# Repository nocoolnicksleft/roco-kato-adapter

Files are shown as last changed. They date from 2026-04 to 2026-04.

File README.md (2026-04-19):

# Roco N (and others) to Kato Unitrack Adapters

Parametric OpenSCAD adapter beds for N-scale [Roco](https://www.roco.cc/) track to connect to the [Kato Unitrack](https://www.katomodels.com/unitrack) system.

The adapters are printed and glued to the underside of Roco track pieces, adding a Kato-compatible sleeper bed with Unijoiner connectors so the Roco pieces plug straight into any Kato Unitrack layout.

25 pre-built configurations are included, covering all common Roco straights, curves and turnouts, plus sleeper belt fillers. Custom pieces and multi-piece layout plates can be generated with a few lines of OpenSCAD.

In general, they should work with any bedless Code 80 system. (Roco N, Fleischmann, Minitrix, Peco, Atlas) From personal experience, I recommend not mixing Minitrix and Roco track on the same base, as the slight difference in height can cause trouble.

You can use the stl files of the pre-built models with any slicer. If you want to work with custom settings or do other modifications you will need OpenSCAD, and Python 3 for the export script.

Use **0.1 mm layer height** and **supports** - both are required for successful prints (see Print Settings below).

---

## Pre-Built Models

Run `./export_stl.sh` to generate all STL files and preview images from the parameter sets in `Roco_Kato_Adapter.json`.

### Turnouts

| Model | Preview |
|---|:---:|
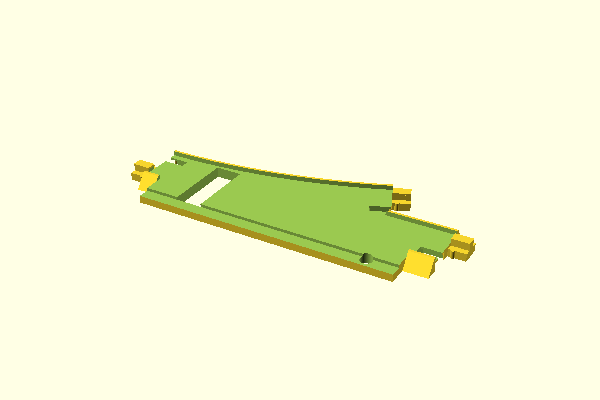
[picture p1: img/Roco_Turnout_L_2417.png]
| **Roco Turnout L 2417** - left, 24°, R194.6, with drive platform |  |
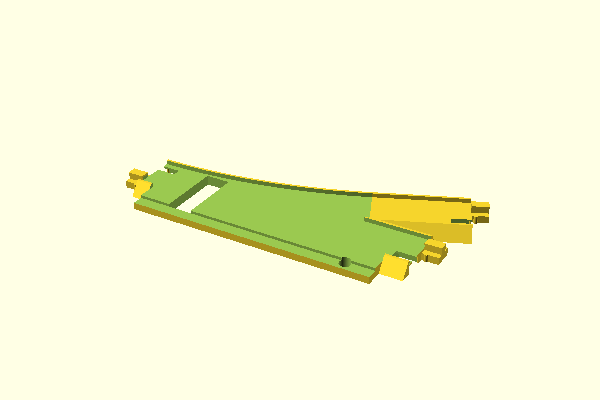
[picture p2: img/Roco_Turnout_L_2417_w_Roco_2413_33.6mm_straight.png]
| **Roco Turnout L 2417 w/ Roco 2413 33.6mm straight** on turnout |  |
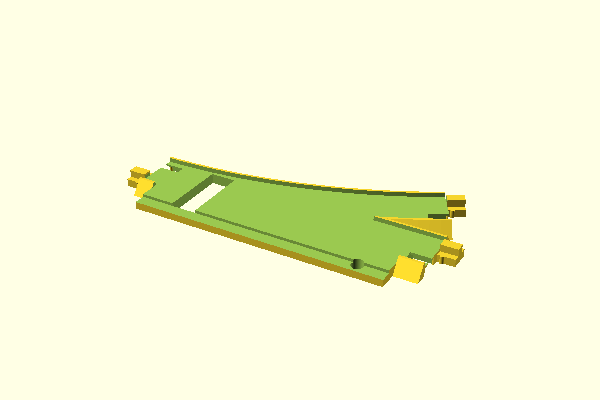
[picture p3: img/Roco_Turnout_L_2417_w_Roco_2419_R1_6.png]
| **Roco Turnout L 2417 w/ Roco 2419 R1 6°** - with 6° curve appended |  |
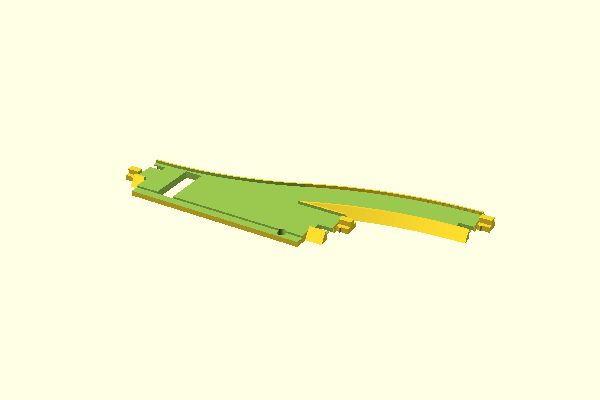
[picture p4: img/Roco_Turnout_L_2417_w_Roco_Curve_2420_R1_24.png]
| **Roco Turnout L 2417 w/ Roco Curve 2420 R1 24°** - with 24° S-curve appended |  |
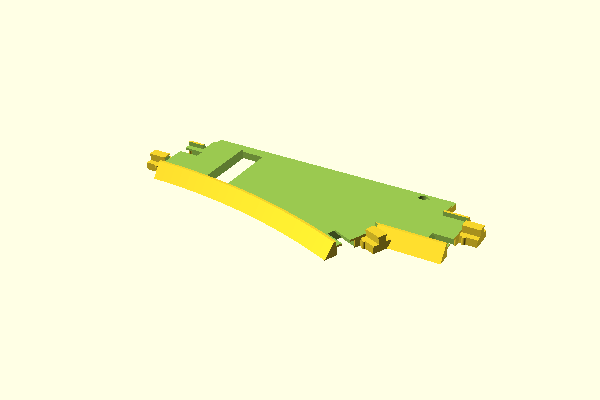
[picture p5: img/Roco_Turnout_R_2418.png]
| **Roco Turnout R 2418** - right 24°, R194.6, with drive platform |  |
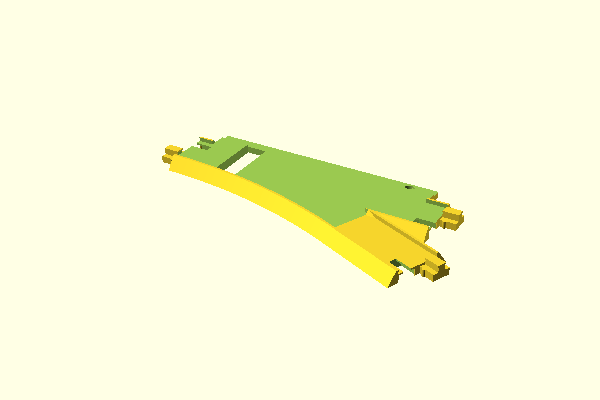
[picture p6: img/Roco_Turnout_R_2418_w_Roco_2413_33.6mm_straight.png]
| **Roco Turnout R 2418 w/ Roco 2413 33.6mm straight** |  |
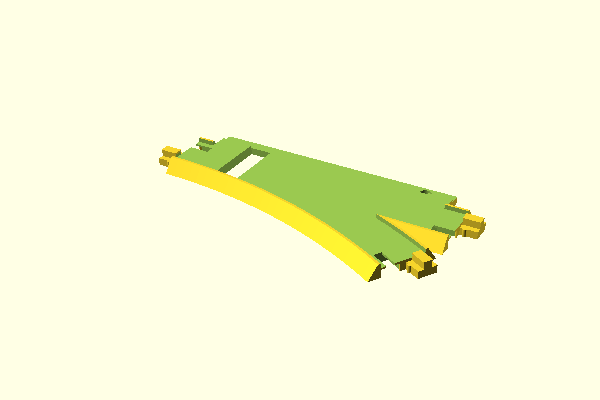
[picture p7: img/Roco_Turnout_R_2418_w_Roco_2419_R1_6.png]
| **Roco Turnout R 2418 w/ Roco 2419 R1 6°** |  |

### Straights and Decoupler

| Model | Preview |
|---|:---:|
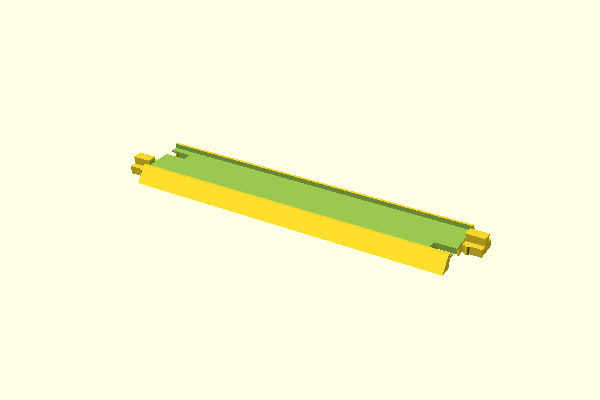
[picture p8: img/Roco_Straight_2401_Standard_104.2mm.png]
| **Roco Straight 2401** - 104.2 mm standard straight |  |
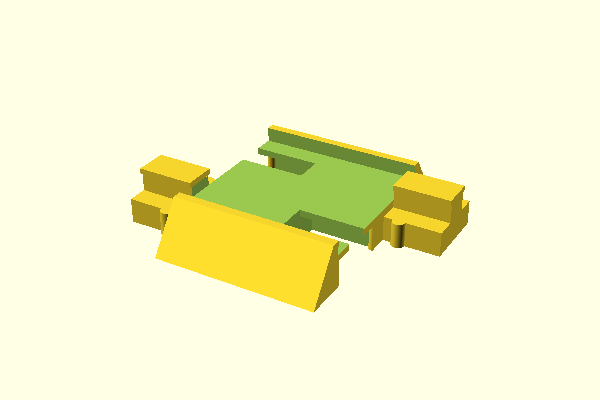
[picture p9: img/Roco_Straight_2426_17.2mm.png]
| **Roco Straight 2426** - 17.2 mm |  |
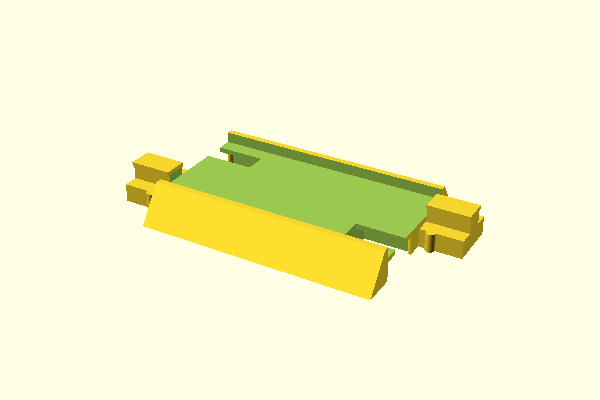
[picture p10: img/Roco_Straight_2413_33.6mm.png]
| **Roco Straight 2413** - 33.6 mm |  |
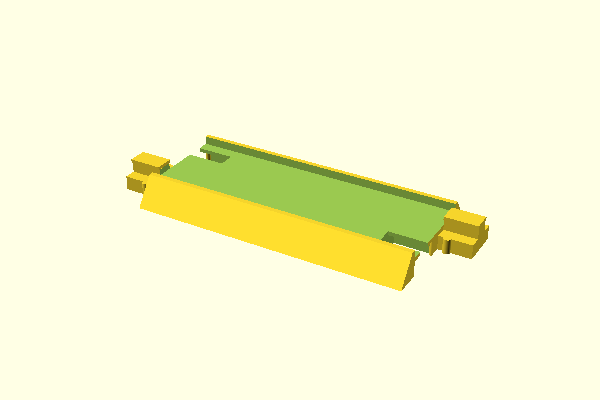
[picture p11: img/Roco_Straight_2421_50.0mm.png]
| **Roco Straight 2421** - 50.0 mm |  |
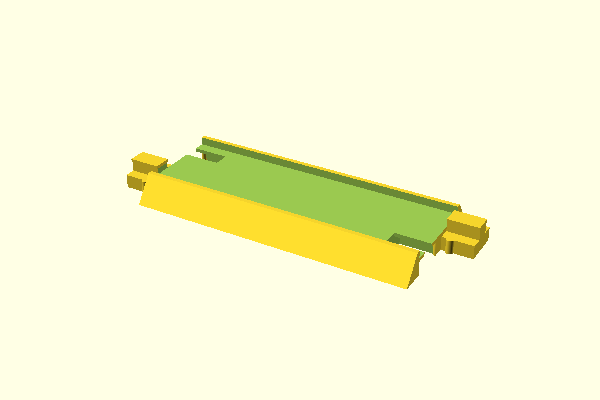
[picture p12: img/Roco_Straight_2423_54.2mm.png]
| **Roco Straight 2423** - 54.2 mm |  |
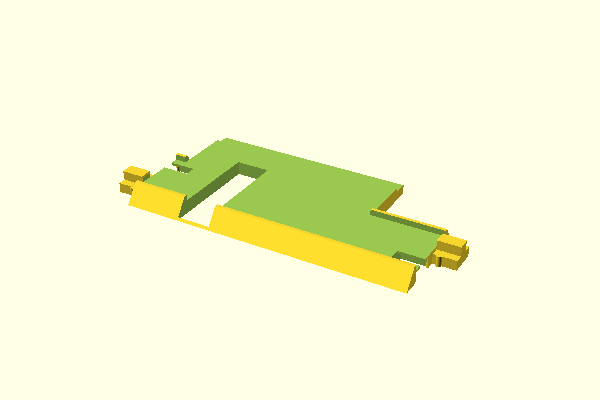
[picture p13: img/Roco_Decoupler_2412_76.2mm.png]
| **Roco Decoupler 2412** - 76.2 mm, with drive platform |  |

### Curves

| R1 (194.6 mm) | R2 (228.2 mm) | R3 / R3A / R4–R6 |
|:---:|:---:|:---:|
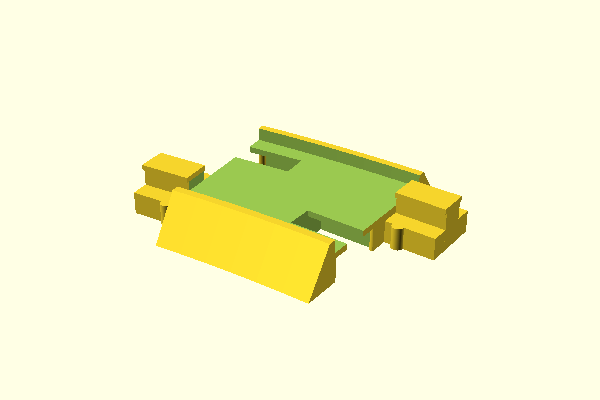
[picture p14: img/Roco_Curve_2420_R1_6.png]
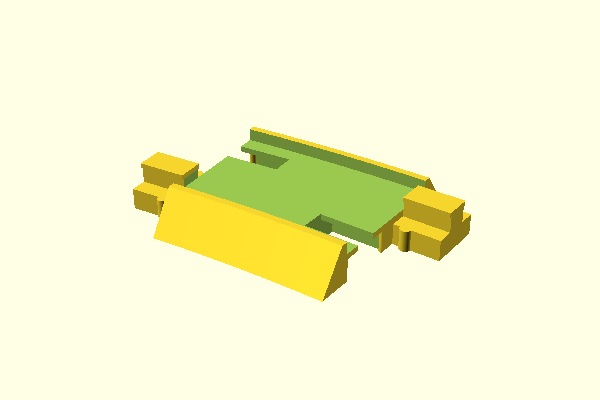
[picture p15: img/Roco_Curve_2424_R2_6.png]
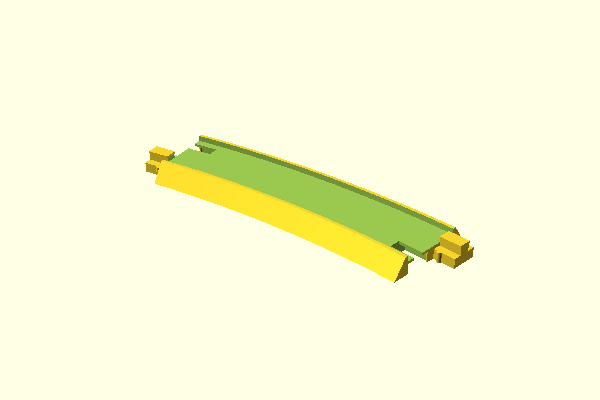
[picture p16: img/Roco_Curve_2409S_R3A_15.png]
| <br>**2420 R1 6°** | <br>**2424 R2 6°** | <br>**2409S R3A 15°** |
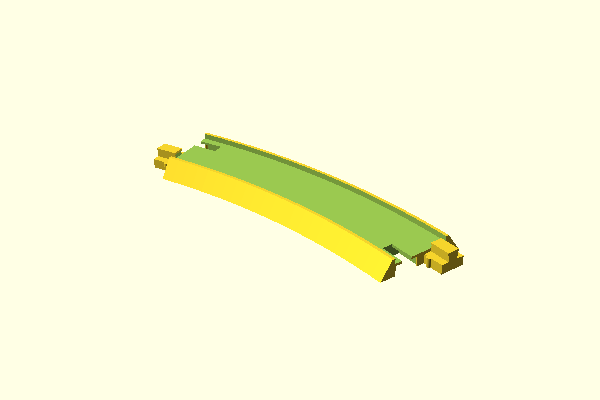
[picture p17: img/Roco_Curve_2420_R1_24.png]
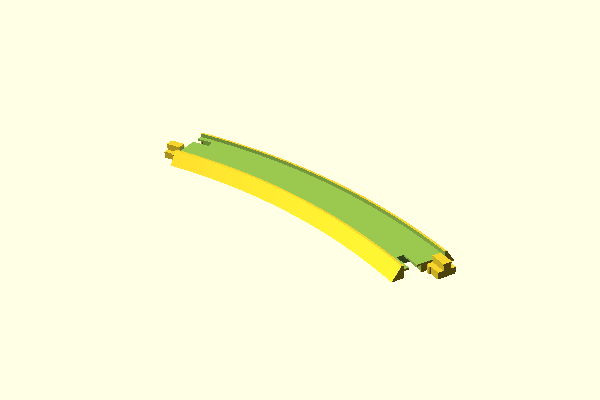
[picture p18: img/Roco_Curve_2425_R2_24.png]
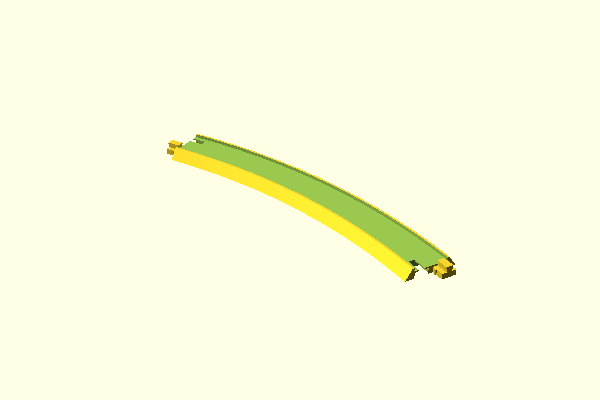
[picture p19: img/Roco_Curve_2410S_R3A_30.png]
| <br>**2420 R1 24°** | <br>**2425 R2 24°** | <br>**2410S R3A 30°** |
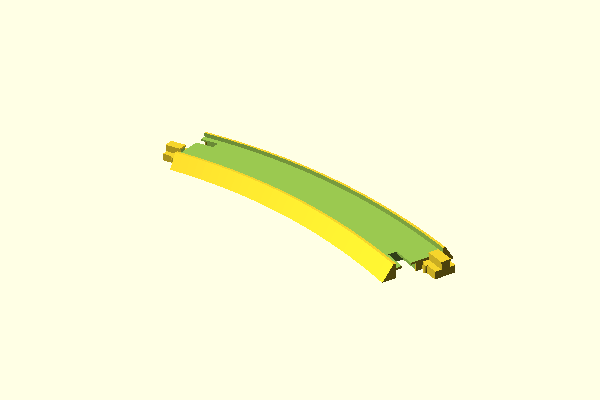
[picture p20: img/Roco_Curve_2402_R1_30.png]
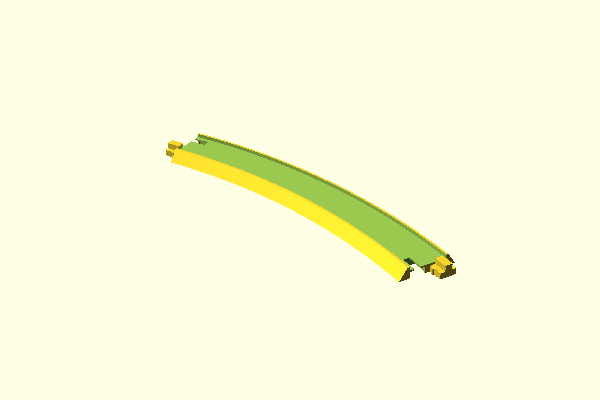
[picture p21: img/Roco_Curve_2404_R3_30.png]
| <br>**2402 R1 30°** | <br>**2403 R2 30°** | <br>**2404 R3 30°** |
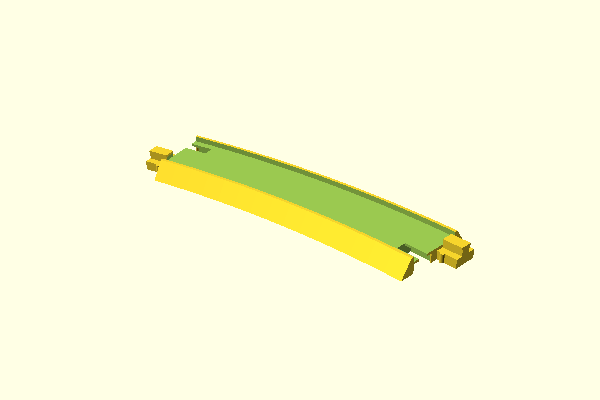
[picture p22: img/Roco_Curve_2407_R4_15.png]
| | | <br>**2407 R4 15°** |
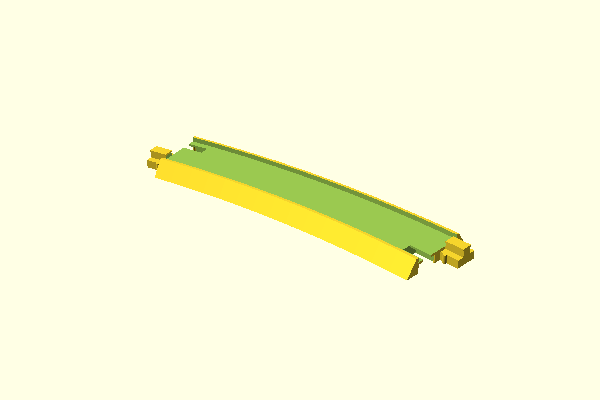
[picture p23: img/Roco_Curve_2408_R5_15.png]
| | | <br>**2408 R5 15°** |
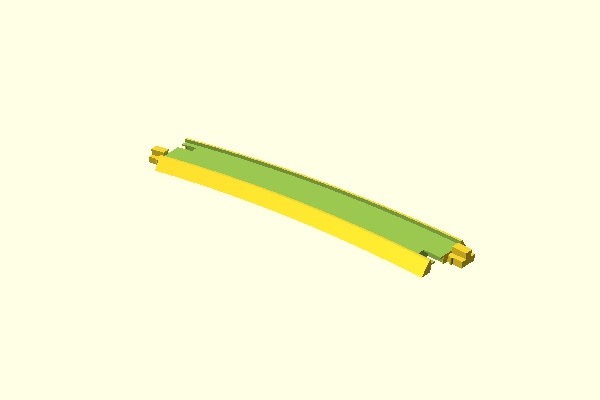
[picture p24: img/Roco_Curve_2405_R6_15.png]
| | | <br>**2405 R6 15°** |

### Sleeper Belts

Standalone strips of Roco-style sleepers for sections of track that need a base but no Kato adapter geometry — for example plain track glued directly to a baseboard. Each belt has sleepers, two longitudinal rail blocks, and rail clamps. End types are configurable per end: **Closed** (full sleepers to the edge), **Open** (rail blocks extend one pitch beyond the last sleeper for butting against an adjacent piece), or **Unijoiner** (right-side rail and sleeper halves cut back to clear Kato Unijoiner connectors, with a centre spine for rigidity).

| Model | Preview |
|---|:---:|
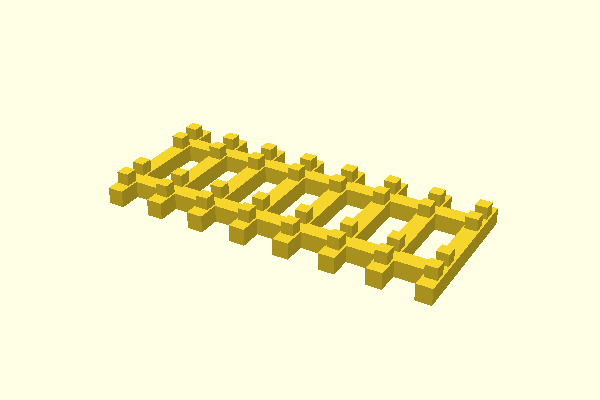
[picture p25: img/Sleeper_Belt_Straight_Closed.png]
| **Sleeper Belt Straight — Closed** — 8 sleepers, both ends closed |  |
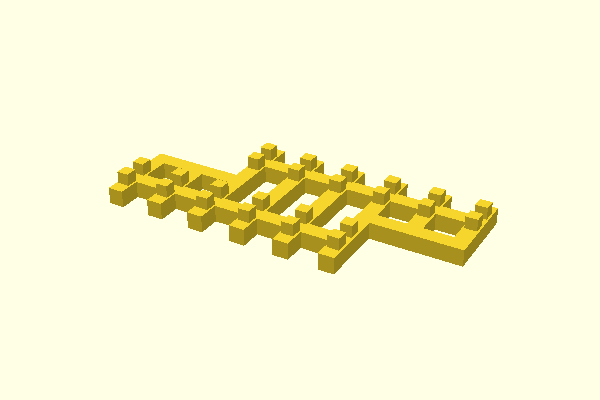
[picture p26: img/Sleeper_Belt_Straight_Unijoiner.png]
| **Sleeper Belt Straight — Unijoiner** — 8 sleepers, Unijoiner cutout at both ends |  |

Open `Roco_Sleeper_Belt.scad` in OpenSCAD to customise belt length, diameter (straight or any Roco/Kato radius), and per-end type. Parameter sets are defined in `Roco_Sleeper_Belt.json` and are included in the batch export.

---

## Usage

### Prepare the track

To accomodate for the Unijoiner receptable,the last two sleepers of the track must be cut and half of them removed. 

If you dont want to cut the sleepers, you can use SCAD to generate versions without Unijoiners and glue them together, or compose an individual model from multiple parts (see below). 

### 1: Print a Pre-Built Model

1. Run `./export_stl.sh` to generate all STL files into the `stl/` folder
   (also generates PNG previews into `img/` for reference).
2. Open the desired STL in desired Slicer and print.

Pre-built configurations are defined in `Roco_Kato_Adapter.json`. To use one directly in OpenSCAD:

```bash
openscad -o my_piece.stl -p Roco_Kato_Adapter.json -P "Roco Turnout L 2417" Roco_Kato_Adapter.scad
```

### 2: Customise a Single Piece

Open `Roco_Kato_Adapter.scad` in OpenSCAD. The **Customizer** panel (View → Customizer) exposes all parameters with drop-down lists of valid values. Adjust, preview, render, then export the STL.

You can also add a new entry to `Roco_Kato_Adapter.json` with your custom parameter values so it becomes part of the batch export.

### 3: Compose a Multi-Piece Layout Plate

For printing multiple connected pieces as a single object, use `layout.scad` as a starting point. It `include`s `Roco_Kato_Adapter.scad` and calls `roco_adapter()` multiple times, using the positioning helpers to chain pieces end-to-end exactly.

```openscad
layout_mode = true;          // suppresses the single-piece default render
include <Roco_Kato_Adapter.scad>

// Piece 1 at origin
roco_adapter(straight_length=104.2, branch_angle=24, radius=194.6, mirrored=false, ...);

// Piece 2 positioned at the straight exit of piece 1
after_straight_exit(sl=104.2)
    roco_adapter(straight_length=33.6, branch_angle=0, enable_entrance_unijoiner=false, ...);

// Piece 3 positioned at the curved exit of piece 1
after_curved_exit(r=194.6, w=24, csl=0, cca=0, m=false)
    roco_adapter(straight_length=104.2, branch_angle=24, enable_entrance_unijoiner=false, ...);
```

**Unijoiner rule for joined pieces:** at every internal joint (where two pieces meet and are printed as one), disable the unijoiner on **both** sides - the exit unijoiner of the upstream piece and the entrance unijoiner of the downstream piece. Only the outer ends that connect to actual Kato Unitrack need unijoiners.

**Always use the connecting_straight_length and connected_curve_angle** properties for pieces directly attached to a turnout. Directly joining other pieces may result in rendering artifacts.

---

## Parameters Reference

### Geometry

| Parameter | Default | Description |
|---|---|---|
| `straight_length` | 104.2 | Length of the straight entry section in mm; 0 to omit |
| `branch_angle` | 24 | Turnout/curve angle in degrees; 0 for straight-only adapter. Values: 0, 6, 15, 24, 30 |
| `radius` | 194.6 | Curve radius in mm. R1=194.6, R2=228.2, R3=261.8, R3A=295.4, R4=329.0, R5=362.6, R6=480 |
| `connecting_straight_length` | 0 | Straight section appended after the branch curve in mm; 0 to omit |
| `connected_curve_angle` | 0 | S-curve angle appended after the branch curve to make exits parallel; 0 to omit |
| `connected_curve_radius` | 194.6 | Radius of the S-curve in mm |
| `mirrored` | false | `false` = left turnout (curve toward +Y); `true` = right turnout (curve toward −Y) |

### Drive Platform (Point Motor Mount)

| Parameter | Default | Description |
|---|---|---|
| `drive_length` | 0 | Length of drive platform in mm; 0 to omit. Use 89 for Roco 2417/2418 |
| `drive_width` | 10 | Width of drive platform in mm |
| `drive_offset` | 6 | Distance from entry to start of drive platform |
| `drive_inset` | 4 | Depth of the recessed slot at the end of the platform |
| `drive_cableslot_diameter` | 4 | Diameter of cable hole in mm |
| `drive_cableslot_offset` | 80 | Position of cable hole from entry |

### Unijoiners

| Parameter | Default | Description |
|---|---|---|
| `enable_entrance_unijoiner` | true | Unijoiner at the entry end of the piece |
| `enable_exit_unijoiner_straight` | true | Unijoiner at the straight exit end |
| `enable_exit_unijoiner_curved` | true | Unijoiner at the curved (branch) exit end |

### Positioning Helpers (layout files only)

| Module | Description |
|---|---|
| `after_straight_exit(sl)` | Translates children `sl` mm along +X (to the straight exit of a piece with `straight_length=sl`) |
| `after_curved_exit(r, w, csl, cca, ccr, m)` | Translates and rotates children to the curved exit. Parameters match the preceding piece's `radius`, `branch_angle`, `connecting_straight_length`, `connected_curve_angle`, `connected_curve_radius`, `mirrored` |

---

## Building

### Assembly

Glue the adapter bed to the underside of the Roco track piece while the piece is connected to Kato Unitrack on all sides. This ensures correct alignment and compensates for any minor tolerance variation.

### Print Settings

| Parameter | Value |
|---|---|
| Layer Height | **0.1 mm** (critical - see note below) |
| Infill | 20% |
| Infill Pattern | Gyroid |
| Supports | **Yes** (critical - see note below) |
| Material | PLA or PETG |
| Walls / Perimeters | 3 |
| Tested on | Prusa MK3, PrusaSlicer 2.x |

> **Critical settings:** 0.1 mm layer height is required to resolve the fine detail of the Unijoiner plug and slot geometry - coarser layers will produce connectors that are too loose or too tight. The overhangs on the connector faces need support from the bed.

PETG is recommended where higher durability or temperature resistance is needed, but PLA works equally well in a typical indoor layout (results on floor heating may vary, depending on your temperature comfort zone).

---

## Physical Calibration

The nominal Roco track dimensions (radius, angle) published in catalogues do not perfectly match the manufactured parts. The Roco R1 turnout (2417/2418), for example, has a measured lateral branch offset of ≈ 16.2 mm versus the nominal 16.82 mm - a difference of less than a millimetre, but enough to cause the track to bow and open the rail contacts when inserted into a tightly printed adapter bed.

The adapter compensates for this silently: all parameters and JSON presets use the official nominal values as usual, and the correction (R1: 24°/194.6 mm → 23.2°/200 mm) is applied internally in `Roco_Kato_Adapter.scad`.

Calibration data is currently only available for **Roco R1**. If you have accurate measurements for other radii (R2–R6) or other manufacturers' track, I would be very pleased if you shared them - for example via a pull request or an issue on the repository. The more data that can be collected, the better the fit will be for everyone.

---
## Tinkerers' little helpers

Optimization, documentation and framework were assisted by AI, namely Github Copilot and Claude Sonnet.

## License

This work is licensed under [CC BY 4.0](https://creativecommons.org/licenses/by/4.0/).  
You are free to share and adapt it for any purpose, provided you give appropriate credit.

Contributions and improvements are welcome - please open a pull request or send them to the author.

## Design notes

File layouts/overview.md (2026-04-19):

# Layout Overview

| Layout | Preview |
|---|---|
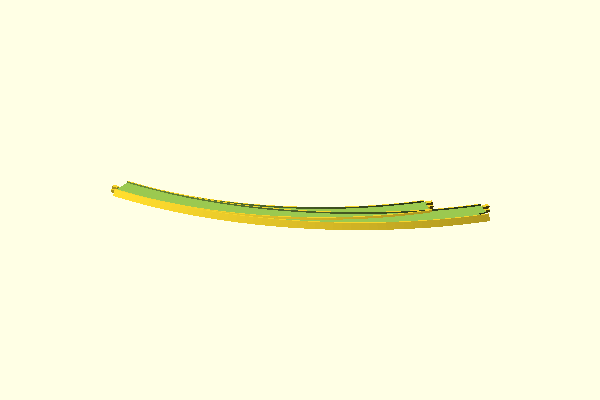
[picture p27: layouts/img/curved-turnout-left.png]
curved-turnout-left
| [Curved Turnout Left](scad/curved-turnout-left.scad) |  |
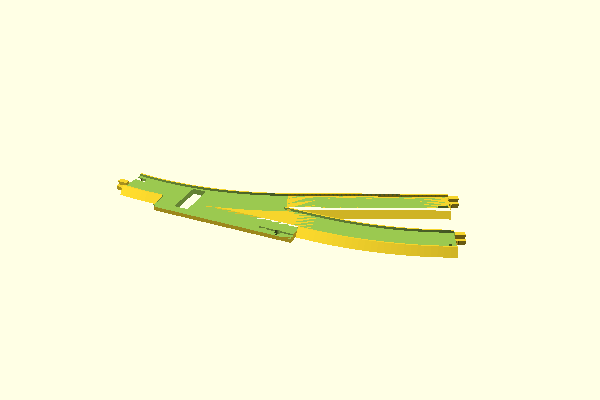
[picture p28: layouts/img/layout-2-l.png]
layout-2-l
| [Layout 2L — Turnout R + Curve R1 + Straight](scad/layout-2-l.scad) |  |
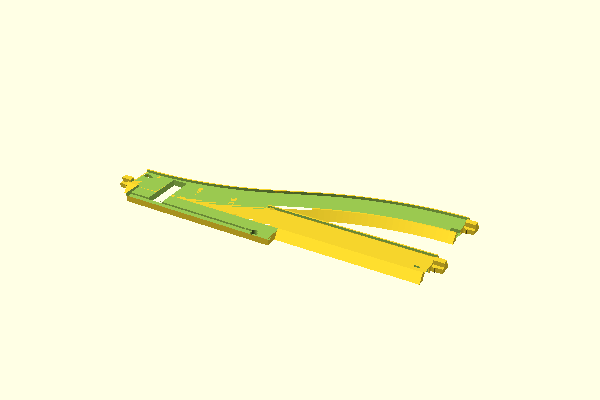
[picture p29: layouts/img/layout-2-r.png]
layout-2-r
| [Layout 2R — Turnout R + S-Curve 24°](scad/layout-2-r.scad) |  |
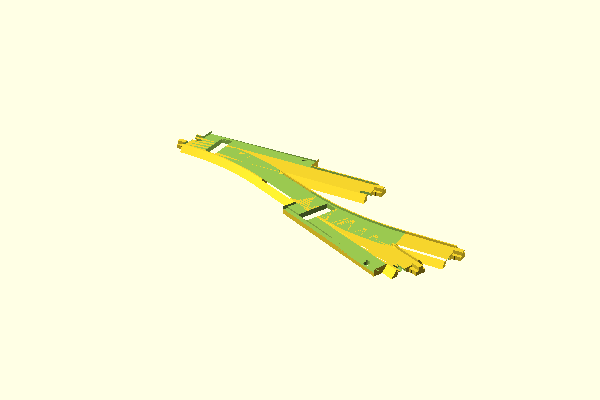
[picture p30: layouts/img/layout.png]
layout
| [Double Turnout Junction (R → L)](scad/layout.scad) |  |

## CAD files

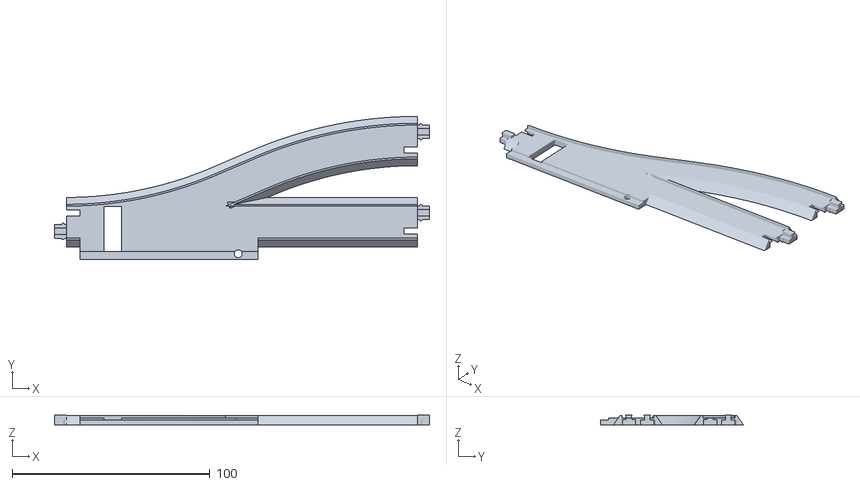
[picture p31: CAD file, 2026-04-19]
layouts/stl/layout-2-r.stl
189.8 x 72.5 x 5.20

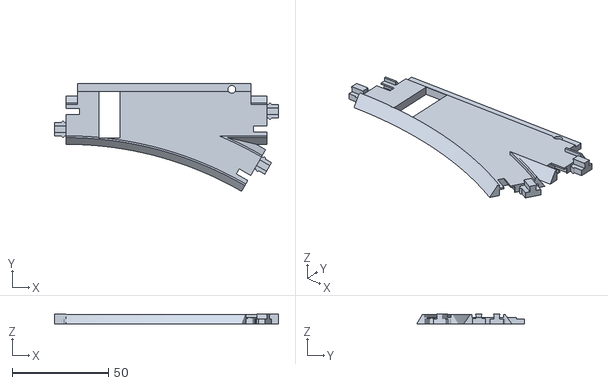
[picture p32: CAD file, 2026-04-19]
Roco_Kato_Adapter.stl
116.2 x 55.9 x 5.20

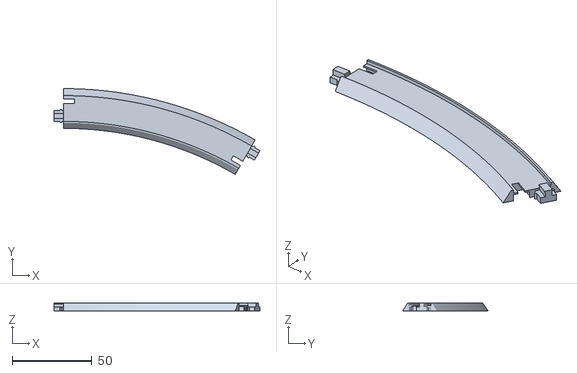
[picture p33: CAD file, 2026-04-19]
stl/Roco_Curve_2403_R2_30.stl
129.4 x 53.9 x 5.20

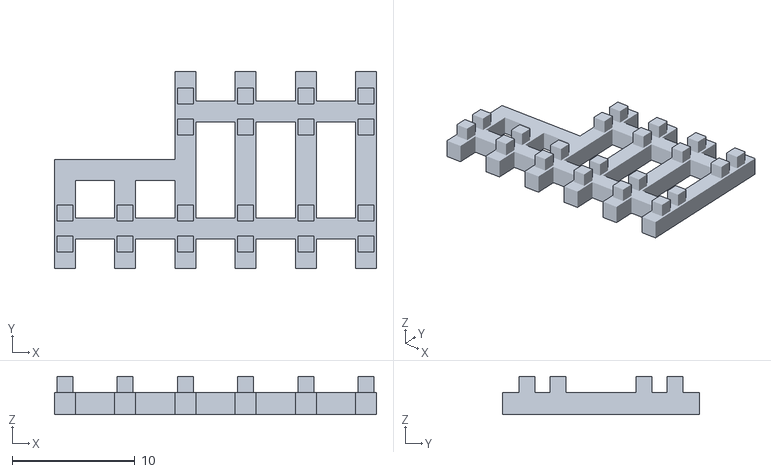
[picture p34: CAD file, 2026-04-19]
tools/Roco_Sleeper_Belt.stl
26.2 x 16.0 x 3.10

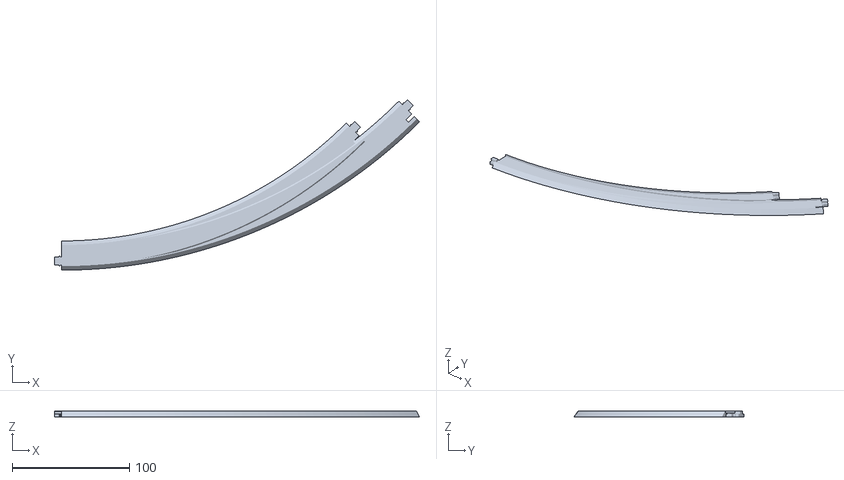
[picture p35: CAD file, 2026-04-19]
layouts/stl/curved-turnout-left.stl
311.8 x 145.6 x 5.20

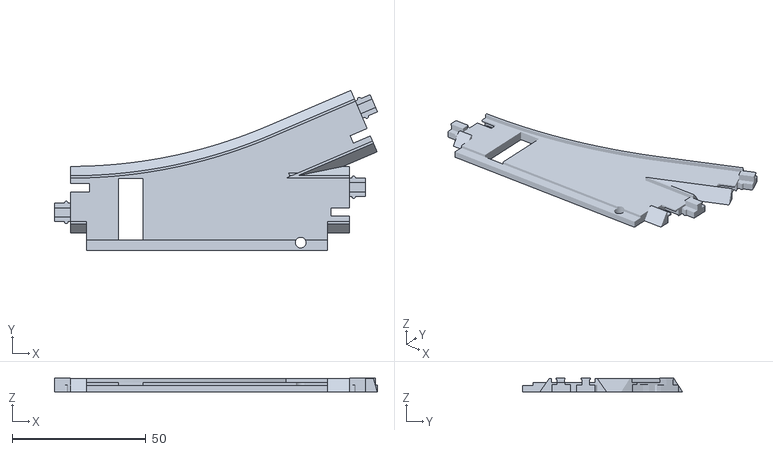
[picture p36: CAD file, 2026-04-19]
stl/Roco_Turnout_L_2417_w_Roco_2413_33.6mm_straight.stl
120.7 x 59.9 x 5.20

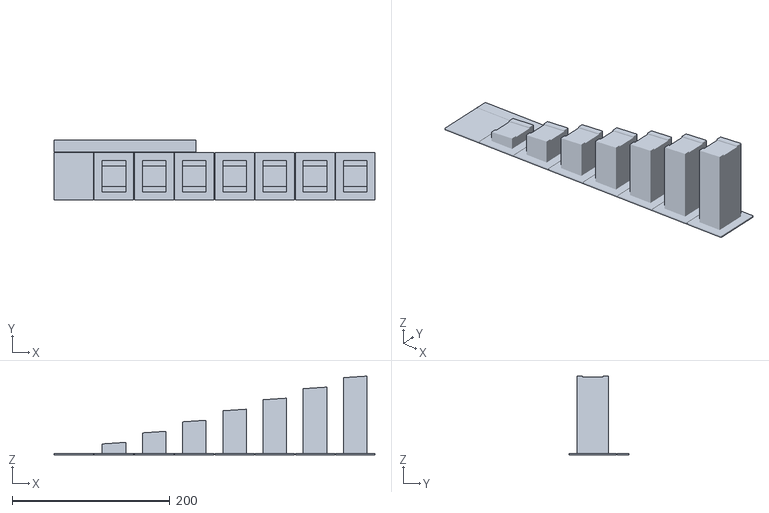
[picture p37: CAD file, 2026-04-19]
tools/Angled_Platform_Pillars.stl
407.0 x 76.0 x 100.0

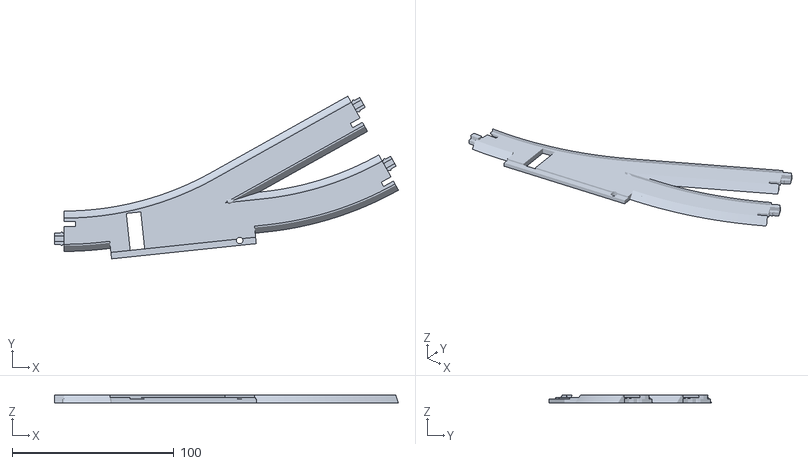
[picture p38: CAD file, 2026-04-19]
layouts/stl/layout-2-l.stl
212.7 x 100.6 x 5.20

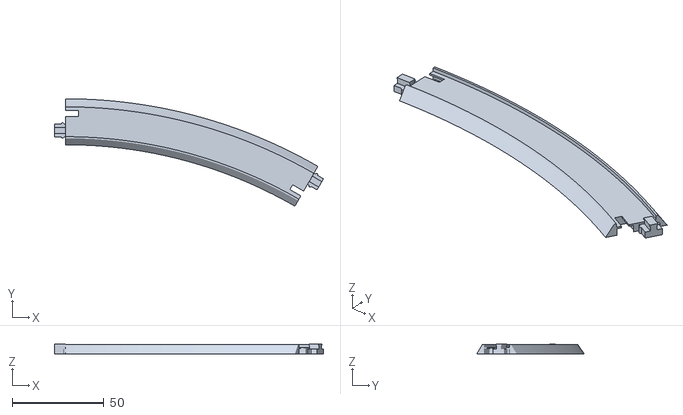
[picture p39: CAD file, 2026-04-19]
stl/Roco_Curve_2404_R3_30.stl
146.2 x 58.4 x 5.20

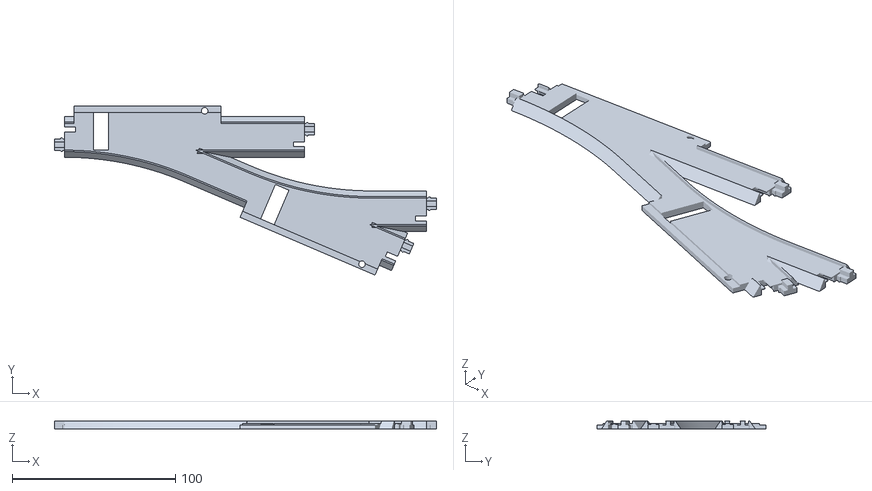
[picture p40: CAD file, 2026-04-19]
layouts/stl/layout.stl
234.1 x 103.7 x 5.20

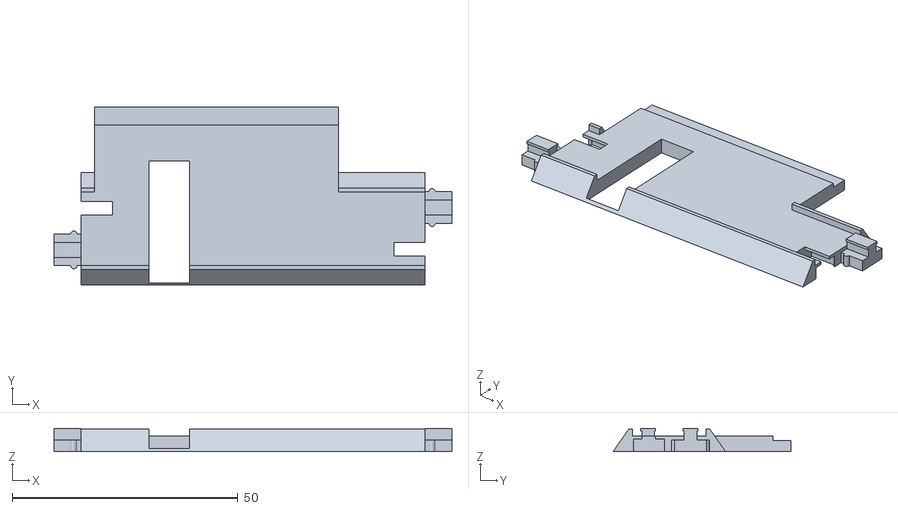
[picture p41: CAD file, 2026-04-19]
stl/Roco_Decoupler_2412_76.2mm.stl
88.2 x 39.5 x 5.20

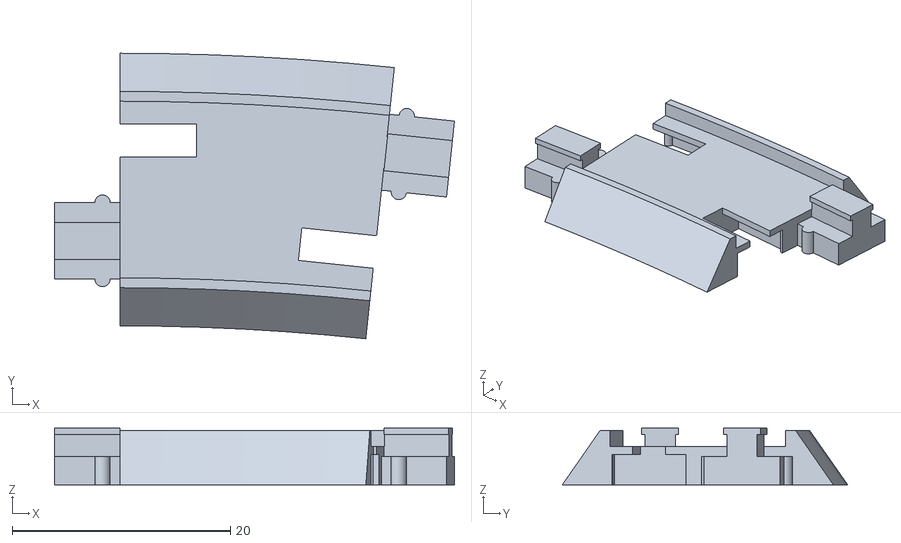
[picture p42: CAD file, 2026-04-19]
stl/Roco_Curve_2424_R2_6.stl
36.7 x 26.2 x 5.20

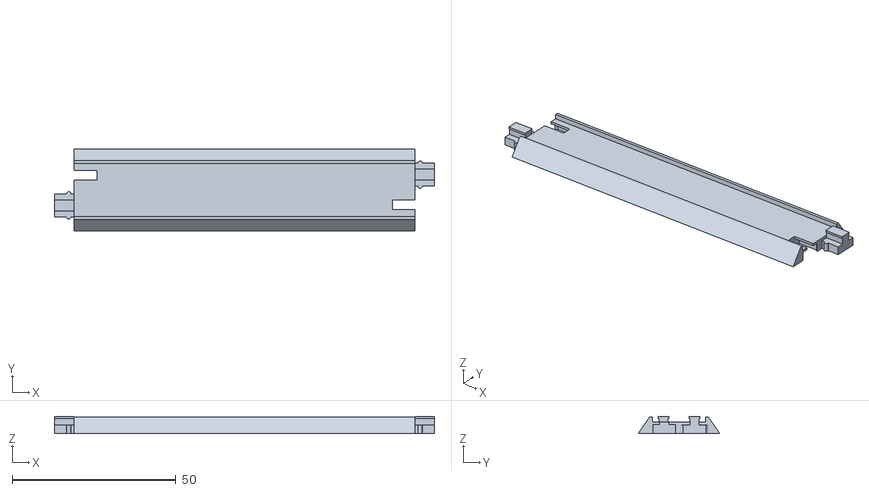
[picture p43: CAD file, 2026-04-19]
stl/Roco_Straight_2401_Standard_104.2mm.stl
116.2 x 25.0 x 5.20

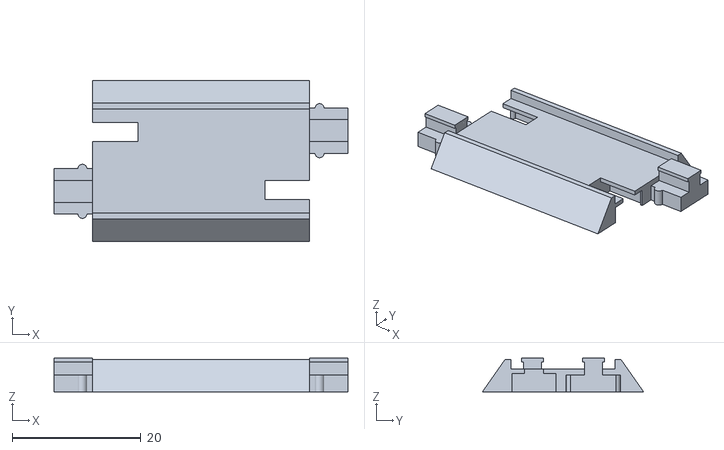
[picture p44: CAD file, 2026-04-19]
stl/Roco_Straight_2413_33.6mm.stl
45.6 x 25.0 x 5.20

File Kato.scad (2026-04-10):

bed_width_top = 18.0;
bed_width_bottom = 25.0;
bed_height = 5.0;

recess_depth = 1.5;
recess_width = bed_width_top - 1.8;
unijoiner_depth = 6;
unijoiner_width = 7;

module bed_profile() {
    polygon(points=[
        [-bed_width_bottom/2, 0],     // bottom left
        [bed_width_bottom/2, 0],      // bottom right
        [bed_width_top/2, bed_height],   // top right
        [-bed_width_top/2, bed_height]   // top left
    ]);
}

module recess_profile() {
    polygon(points=[
        [-recess_width / 2, bed_height - recess_depth],     // bottom left
        [recess_width / 2, bed_height - recess_depth],      // bottom right
        [recess_width / 2, bed_height + 1],   // top right
        [-recess_width / 2, bed_height + 1]   // top left
    ]);
}

module full_profile() {
    difference() {
        bed_profile();
        recess_profile();
    } 
}

module curved_section(r, w) {
    // Curved sleeper bed via rotational extrusion
  rotate_extrude(angle = w, $fn = 360) 
    translate([r,0, 0]) 
        full_profile();
}

module curved_bed(r, w) {
    // Curved sleeper bed via rotational extrusion
  rotate_extrude(angle = w, $fn = 360) 
    translate([r,0, 0]) 
        bed_profile();
}

module curved_recess(r, w) {
  // Curved recess via rotational extrusion
  rotate_extrude(angle = w+0.01, $fn = 360) 
    translate([r,0, 0]) 
        recess_profile();
}

module straight_section(l) {
   rotate(a=[90,0,90])
    linear_extrude(height= l)
        full_profile();
}

module straight_bed(l) {
   rotate(a=[90,0,90])
    linear_extrude(height= l)
        bed_profile();
}

module straight_recess(l) {
   rotate(a=[90,0,90])
    linear_extrude(height= l)
        recess_profile();
}


module unijoiner_receptable(reverse=false,rims=true) {
    slotwidth = 3;
    width_bottom = unijoiner_width;
    height_bottom = 2.8;
    translate([0, reverse ? bed_width_top/4 - unijoiner_width/2 - 1.6 : -bed_width_top/4 - unijoiner_width/2 - 0.4, 0])    
    difference() {
        union() {
            cube([unijoiner_depth + 1, unijoiner_width + 0.8, height_bottom]);
            translate([0,(unijoiner_width + 0.8)/ 2 - slotwidth / 2 ,0]) 
                cube([unijoiner_depth + 1, slotwidth, bed_height - recess_depth]); 
            $fn=360;
            
        }
        if (rims) {
            translate([unijoiner_depth + 0.8 , 0, 0])
                cylinder(h=height_bottom, r=0.5, $fn=360);
            translate([unijoiner_depth + 0.8, width_bottom + 0.8, 0])
                cylinder(h=height_bottom, r=0.5, $fn=360);
        }
    }
}

module unijoiner_plug() {
    width_bottom = unijoiner_width;
    width_middle = 2.8;
    height_bottom = 2.6;
    height_middle = 4.6;

    width_top= width_middle + 0.6;
    height_top = 0.6;
    
    translate([0, bed_width_top/4 - unijoiner_width/2 + 0.2, 0])   
    difference() {
        union() {
            cube([unijoiner_depth, width_bottom, height_bottom]); 
            
            translate([0 + 0.001, width_bottom / 2 - width_middle / 2 + 0.001, 0])
                cube([unijoiner_depth, width_middle, height_middle]); 
  
            translate([0 + 0.002, width_bottom / 2 - width_top / 2 + 0.002, height_middle])
                cube([unijoiner_depth, width_top, height_top]); 

            translate([unijoiner_depth / 3 -0.4, 0, 0])
                cylinder(h=height_bottom, r=0.7, $fn=360);
            translate([unijoiner_depth / 3 -0.4, width_bottom, 0])
                cylinder(h=height_bottom, r=0.7, $fn=360);
        }
    }
}

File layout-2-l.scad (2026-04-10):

/*
    layout.scad - Multi-piece layout plate.

    Diagram (curved exits branch away from the straight axis):

        [1: Right turnout 2418]
               │ (curved exit, -Y direction since mirrored)
        [2: 33.6mm straight]
               │
        [3: Left turnout 2417]
               │ (curved exit, +Y in local frame)
        [4: 33.6mm straight]

    Positioning rules:
      - after_straight_exit(sl) : step forward sl mm along the current +X axis
      - after_curved_exit(r, w, csl, cca, m) : jump to the curved exit of the
        preceding piece, matching its exit direction
      - Nest calls to chain: each outer call sets the frame for the inner ones.
      - At every joint between two pieces, disable the unijoiner on BOTH sides:
        the exit unijoiner of the upstream piece and the entrance unijoiner of
        the downstream piece.  Because the pieces are printed as one merged
        object, no physical unijoiner connector is needed there.
*/

layout_mode = true;      // suppresses the single-piece preview render
include <Roco_Kato_Adapter.scad>

// ── Piece 1: Roco Turnout R 2418 (right/mirrored) ────────────────────────────

roco_adapter(
    straight_length             = 104.2,
    branch_angle                = 30,
    radius                      = 194.6,
    connecting_straight_length  = 0,
    connected_curve_angle       = 0,
    drive_length                = 90,
    drive_width                 = 10,
    drive_offset                = 7,
    drive_inset                 = 4,
    drive_cableslot_diameter    = 4,
    drive_cableslot_offset      = 80,
    enable_entrance_unijoiner       = true,
    enable_exit_unijoiner_straight  = false,
    enable_exit_unijoiner_curved    = true,  // joins piece 2
    mirrored                    = false
);




// ── Piece 2: Roco Curve 2420 R1 24° - curved exit of piece 1 ──────────────
after_straight_exit(sl = 104.2)
    roco_adapter(
            connecting_straight_length = 0,
            drive_length = 0,
            enable_entrance_unijoiner = false,
            enable_exit_unijoiner_straight = true,
            straight_length = 0,
            radius = 194.6,
            branch_angle = 24,
            mirrored = false
    );

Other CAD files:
stl/Roco_Turnout_L_2417_w_Roco_2419_R1_6.stl
stl/Roco_Turnout_L_2417.stl
stl/Roco_Straight_2426_17.2mm.stl
stl/Roco_Curve_2410S_R3A_30.stl
layout-2-r.scad
layout.scad
Roco_Kato_Adapter.scad
layouts/scad/curved-turnout-left.scad
layouts/scad/layout-2-l.scad
layouts/scad/layout-2-r.scad
layouts/scad/layout.scad
stl/Roco_Curve_2402_R1_30.stl
stl/Roco_Curve_2405_R6_15.stl
stl/Roco_Curve_2407_R4_15.stl
stl/Roco_Curve_2408_R5_15.stl
stl/Roco_Curve_2409S_R3A_15.stl
stl/Roco_Curve_2420_R1_24.stl
stl/Roco_Curve_2420_R1_6.stl
stl/Roco_Curve_2425_R2_24.stl
stl/Roco_Straight_2421_50.0mm.stl
stl/Roco_Straight_2423_54.2mm.stl
stl/Roco_Turnout_L_2417_nojoin.stl
stl/Roco_Turnout_L_2417_w_Roco_Curve_2420_R1_24.stl
stl/Roco_Turnout_R_2418.stl
stl/Roco_Turnout_R_2418_nojoin.stl
stl/Roco_Turnout_R_2418_w_Roco_2413_33.6mm_straight.stl
stl/Roco_Turnout_R_2418_w_Roco_2419_R1_6.stl
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

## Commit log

2026-04-06 Added README
    [Roco_Kato_Adapter.scad, Roco_Kato_Adapter.stl, Unijoiner Test.stl]
2026-04-06 Added mirrored and exports
    [Kato.scad, Roco_Curve_2402_R1_30.stl, Roco_Curve_2420_R1_24.stl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]
2026-04-07 Added curve and parameterSets
    [Kato.scad, Roco_Curve_2402_R1_30.stl, Roco_Curve_2403_R2_30.stl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]
2026-04-07 Translate all German variable names and comments to English
    [Kato.scad, Roco_Kato_Adapter.scad, Roco_Turnout_L_2417_nojoin.stl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]
2026-04-07 Made Previews
    [Roco_Curve_2402_R1_30.stl, Roco_Curve_2403_R2_30.stl, Roco_Curve_2404_R3_30.stl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]
2026-04-08 Small beautifications
    [Kato.scad, onepiece.stl]
2026-04-08 Fixed R1
    [layout.scad, onepiece.stl]
2026-04-08 Added silent correction of geometry
    [Roco_Curve_2405_R6_15.stl, Roco_Curve_2409S_R3A_15.stl, Roco_Curve_2420_R1_24.stl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]
2026-04-10 Refined connectors
    [Kato.scad, Roco_Curve_2402_R1_30.stl, Roco_Curve_2403_R2_30.stl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]
2026-04-10 Minor text fixes
    [Roco_Kato_Adapter.scad, layout-2-l.scad, layout-2-r.scad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]
2026-04-19 Added tool models
    [Angled_Platform_Pillars.scad, Angled_Platform_Pillars.stl, Roco_Sleeper_Belt.scad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]
2026-04-19 Reorganized layouts
    [curved-turnout-left.scad, curved-turnout-left.stl, layout-2-l.scad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]
2026-04-19 Model enhancements
    [Roco_Curve_2402_R1_30.stl, Roco_Curve_2403_R2_30.stl, Roco_Curve_2404_R3_30.stl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]
